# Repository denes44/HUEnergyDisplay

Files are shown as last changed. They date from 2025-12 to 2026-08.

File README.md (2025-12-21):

# HUEnergyDisplay





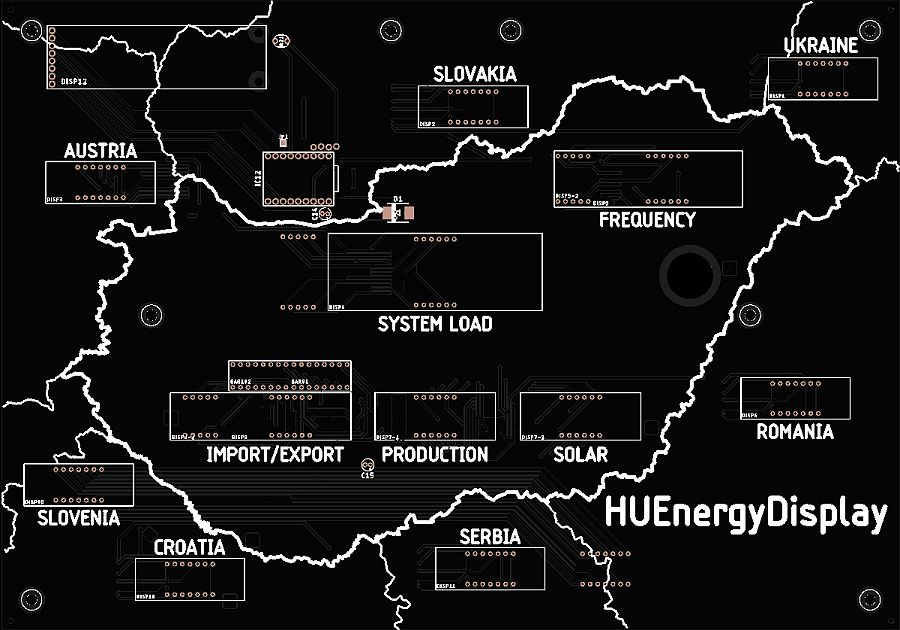
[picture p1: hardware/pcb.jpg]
Design of the PCB


Custom 7 segment display for displaying the hungarian power or natural gas
transmission system.

The display has multiple 7 segment displays for different data arranged around
the map of the country, and it also has a 2.25" TFT display for displaying
status and other miscellaneous data.

| **Power** | **Gas** |
| --- | --- |
| System load | Total consumption |
| Frequency | Storage container ratio |
| Power plant production | Production |
| Solar production | Storage extraction |
| Import/export to neighbouring contries, and total balance | Import/export to neighbouring contries, and total balance |
| Detailed power plant production on the TFT display | |

If you are looking for the easiest way to **start using your display
under Home Assistant:** ***[Home Assistant Quick Start Guide](HomeAssistant.md)***

## Hardware

The hardware of this project is a 300 mm x 210 mm sized bare PCB,
designed to fit into a picture frame, especially the IKEA RÖDALM.

More information about the hardware (PCB size, WiFi controller, display, etc.),
can be found in the **[hardware](hardware/README.md)** folder.

### ESPHome

The display uses an ESP32-S3 controller and ESPHome as it's firmware.

More information about the ESPHome firmware can be found in the
**[esphome](esphome/README.md)** folder.

## API

The display is using it's own private API, which collect and processes
the neccessary datas, and present it in an easy JSON format to the on-board
controller.

The API requires an API Key. By default, the displays are using the MD5 hash
of the MAC address of the controller as the API Key.

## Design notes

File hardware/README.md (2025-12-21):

# HUEnergyDisplay - Hardware



## PCB Size

Design of the PCB

The size of the PCB is 300 mm x 210 mm.

It fits perfectly in an IKEA RÖDALM 21x30 cm picture frame
(IKEA article number is 005.488.82).
The edge of the PCB is designed to not interfere with the edge
of the picture frame.

There is a template available to drill the holes at the back of the
picture frame, so you can mount the PCB: [pcb_cutout.pdf](pcb_cutout.pdf)

## Schematics

## Controller

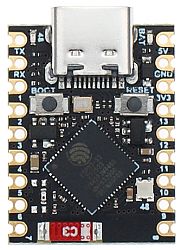
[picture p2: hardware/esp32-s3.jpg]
Photo of the ESP32 controller

The PCB is designed to accomodate an ESP32-S3 SuperMini controller.

The firmware is ESPHome, you can find the configuration to it in the
[esphome](../esphome/README.md) folder.

### GPIO Pinout

| Pin | Function |
| --- | --- |
| GPIO0  | Boot button |
| GPIO1  | MAX7219 CLK |
| GPIO12 | MAX7219 MOSI |
| GPIO13 | MAX7219 CS |
| GPIO5-10 | 2.25" TFT display |
| GPIO4  | Ambient light sensor |
| GPIO48 | Status Led (currently not used) |

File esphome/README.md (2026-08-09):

# HUEnergyDisplay - ESPHome Firmware

Made for ESPHome logo



## Firmware

The default firmware to use is [huenergydisplay-esp32s3.factory.bin](https://github.com/denes44/HUEnergyDisplay/releases/download/esphome-latest/huenergydisplay-esp32s3.factory.bin).
With this firmware you can use [Improv via BLE](https://esphome.io/components/esp32_improv)
or [Improv via Serial](https://esphome.io/components/improv_serial)
to provision your device.

## Configuration

### Factory

The factory firmware uses the [huenergydisplay.factory.yaml](huenergydisplay.factory.yaml)
configuration file.

### ESPHome Dashboard

To import the configuration to your ESPHome Dashboard, use the [huenergydisplay.yaml](huenergydisplay.yaml)
file.

By default this file imports the core configuration from GitHub dynamically.

### Core functionality

Both of these config files import the [huenergydisplay-core.yaml](huenergydisplay-core.yaml)
configuration file which contains the core functionality for the device.

## Firmware update

### Factory

In this configuration mode, the device uses the built-in [HTTP Update platform](https://esphome.io/components/update/http_request.html).

If an update is available, you can update the device from the Web GUI, or from
Home Assistant directly, if you added the device to Home Assistant.

### ESPHome Dashboard

In this configuration mode, a text sensor called `Remote YAML Update`
is provided, to indicate if the remote core yaml configuration is newer than
what's installed on the device.

If you do a firmware install from the dashboard, the build process will use
the new core yaml file from GitHub dynamically.

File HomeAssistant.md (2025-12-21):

# HUEnergyDisplay - Home Assistant Quick Start Guide

## Installing the firmware

If you got your display with the controller and firmware preinstalled,
you can skip to the next step.

## Connect the display to WiFi

### Using Improv Wi-Fi

- With your phone (or other BLE capable device), go to [improv-wifi.com](https://www.improv-wifi.com/)
- At `Improv via BLE` click `Connect device to Wi-Fi`
- Select the device, and click `Pair`
- Enter your Wi-Fi network's credentials (SSID and password) and click `Save`
- The device will now connect to the selected Wi-Fi network

### Connecting to the Wi-Fi AP provided by the device

## Add the display to Home Assistant

After connecting the display to your WiFi network, click on this button
to open the integrations page in Home Assistant:



Home Assistant should automatically recognize the device from the network.

If not, you can manually add itt using the ESPHome integration:



## Using the device in Home Assistant

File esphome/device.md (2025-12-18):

---
title: HUEnergyDisplay
date-published: 2025-12-19
type: misc
standard: global
board: esp32
project-url: https://github.com/denes44/HUEnergyDisplay/tree/main/esphome
made-for-esphome: True
difficulty: 1
---

Custom 7 segment display for displaying the hungarian power or natural gas
transmission system.

The hardware of this project is a 210 mm x 300 mm sized bare PCB,
designed to fit into a picture frame, especially the IKEA RÖDALM.

The display has multiple 7 segment displays for different data arranged around
the map of the country, like: system load, frequency (for power), import/export
for the neighbouring countries, production, etc.

It also has a 2.25" TFT display for displaying status and other miscellaneous
data.

The 7 segment displays are driven by MAX7219 ICs (11 ICs for 12 displays in
total).

## GPIO Pinout

| Pin | Function |
| --- | --- |
| GPIO0  | Boot button |
| GPIO1  | MAX7219 CLK |
| GPIO12 | MAX7219 MOSI |
| GPIO13 | MAX7219 CS |
| GPIO5-10 | 2.25" TFT display |
| GPIO4  | Ambient light sensor |
| GPIO48 | Status Led (currently not used) |

## Basic Configuration

The [Latest configuration](https://github.com/denes44/HUEnergyDisplay/tree/main/esphome)
can be found on the project's GitHub repo.

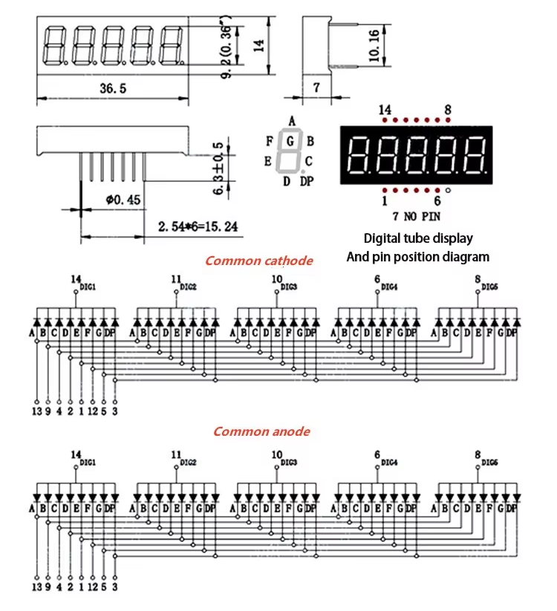
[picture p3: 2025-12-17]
datasheet/display_14mm_5.png

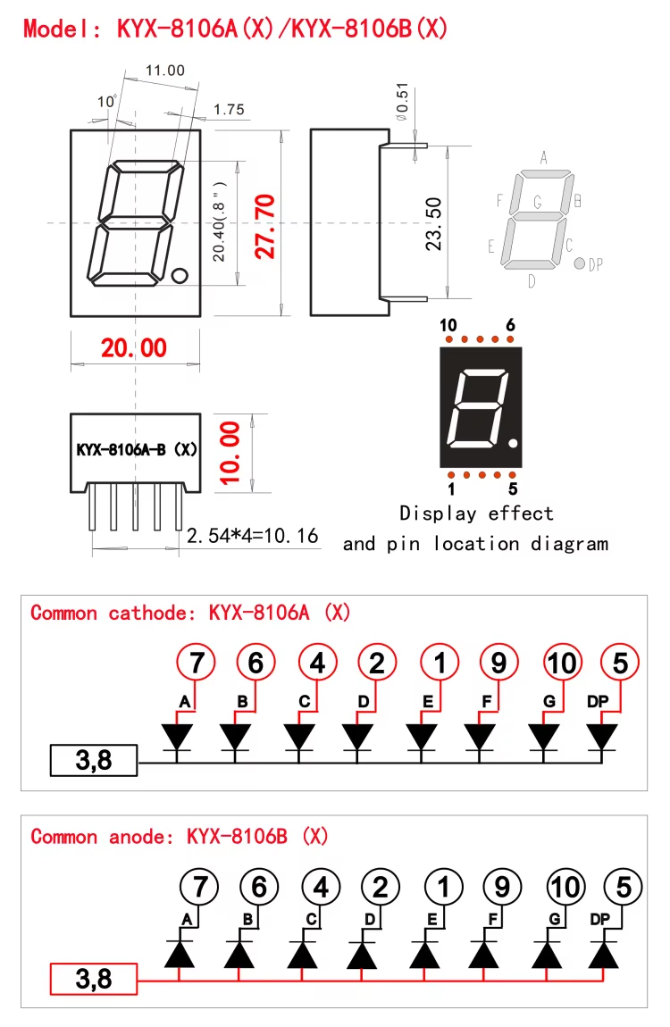
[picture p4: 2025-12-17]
datasheet/display_26mm_1_KYX-8106A_2.png

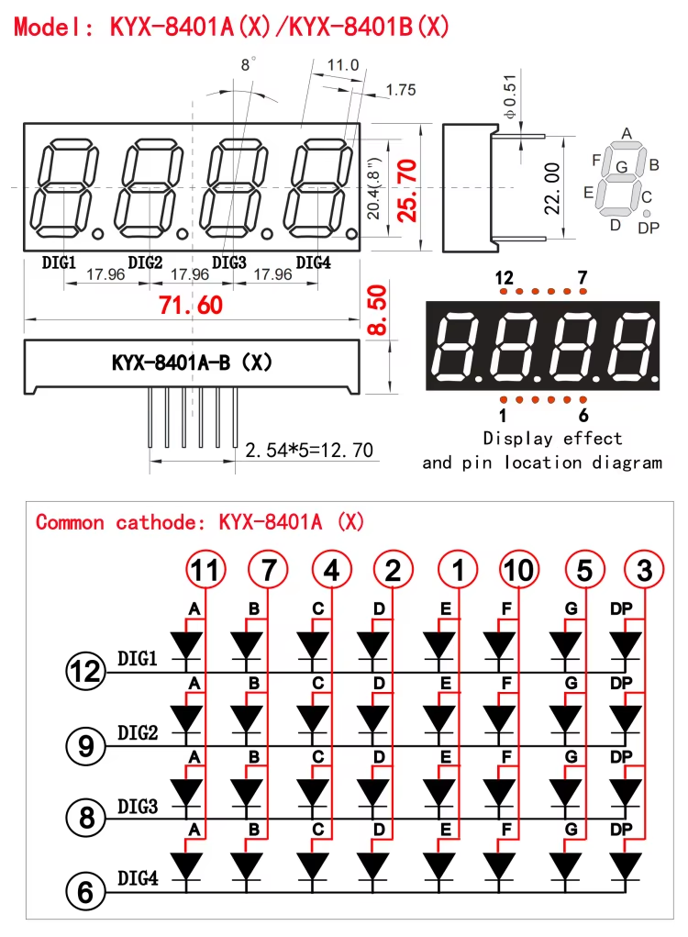
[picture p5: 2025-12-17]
datasheet/display_26mm_4_KYX-8401A_2.png

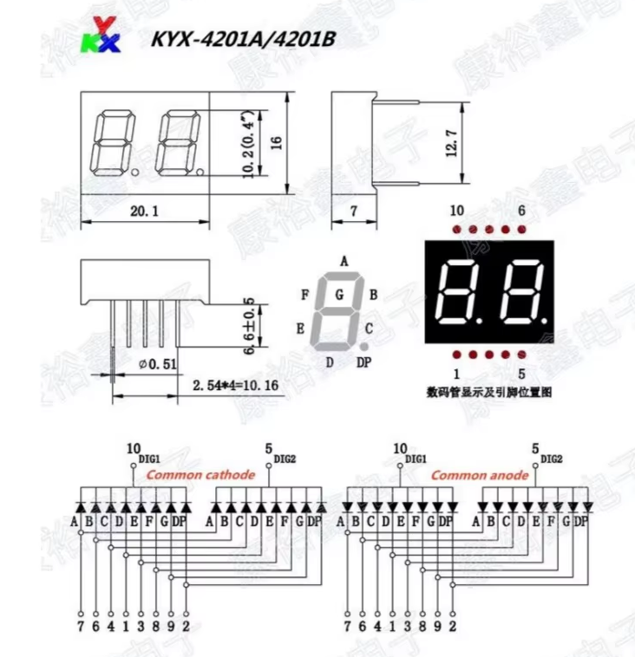
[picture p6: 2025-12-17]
datasheet/display_16mm_2_KYX-4201A.png

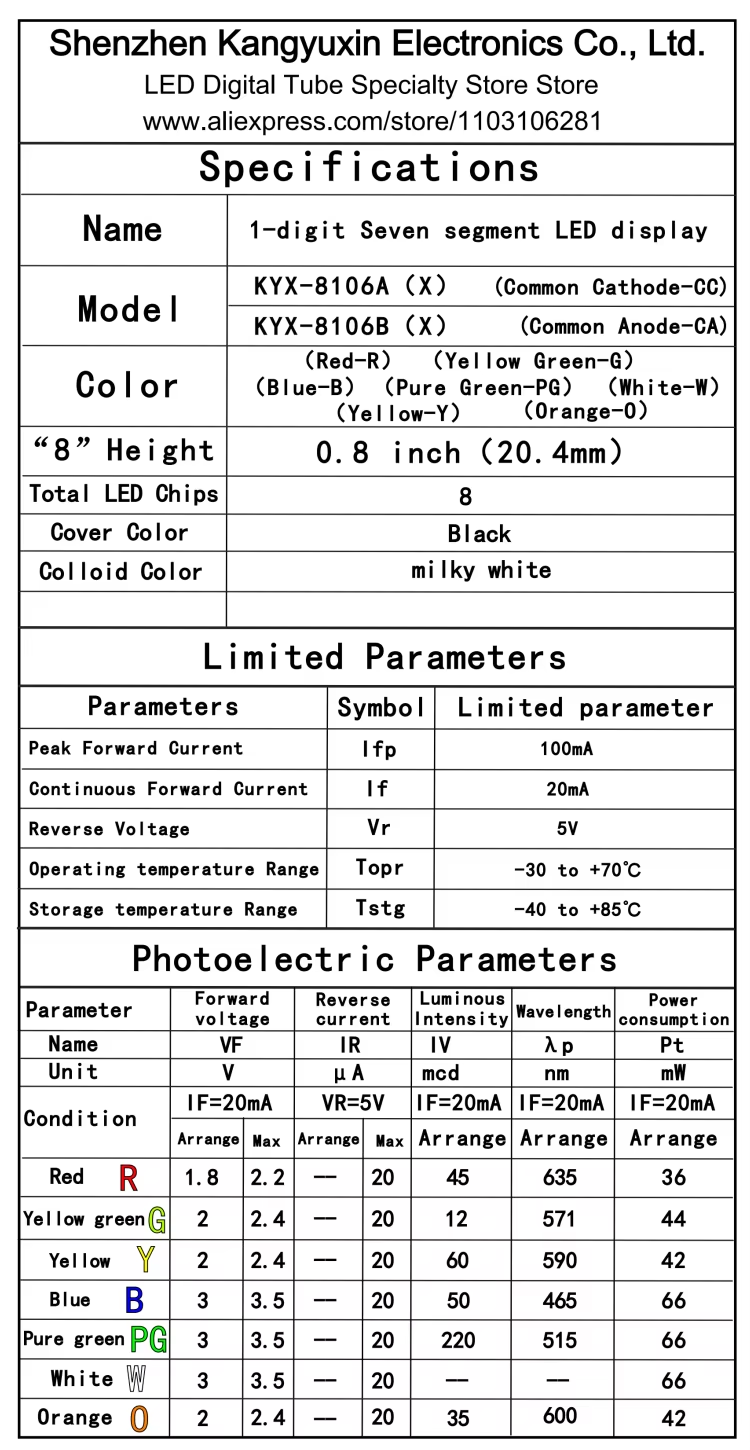
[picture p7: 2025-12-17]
datasheet/display_26mm_1_KYX-8106A_1.png

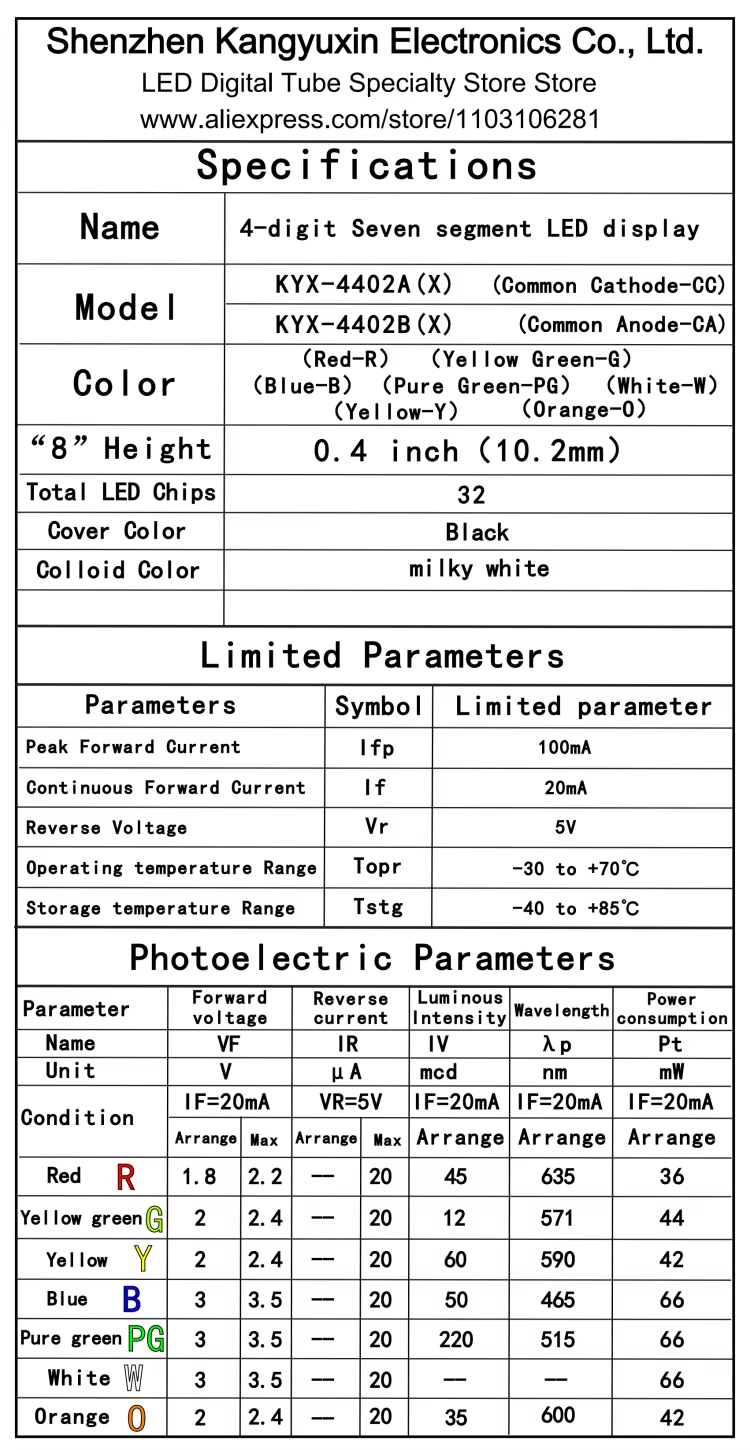
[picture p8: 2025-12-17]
datasheet/display_16mm_4_KYX-4402A_1.png

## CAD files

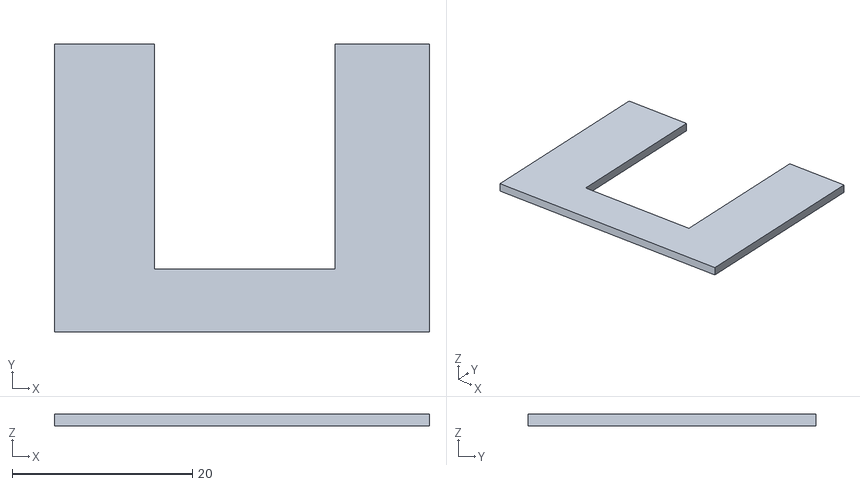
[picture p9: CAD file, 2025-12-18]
3d/14mm_5.stl
41.6 x 32.0 x 1.30

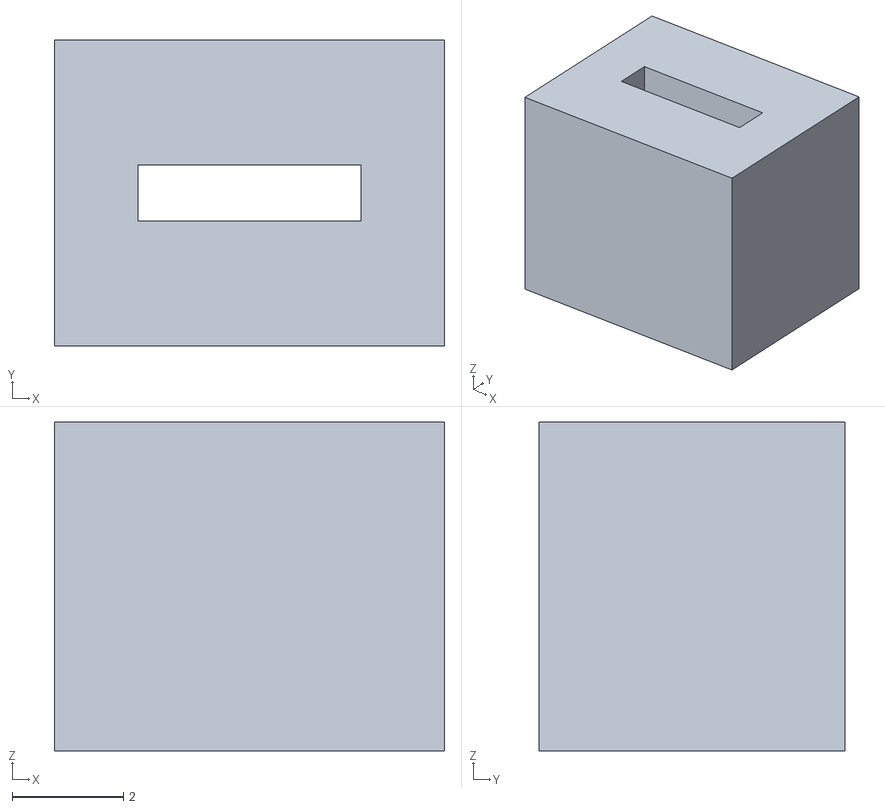
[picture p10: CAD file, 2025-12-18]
3d/sensor_spacer.stl
7.00 x 5.50 x 5.90

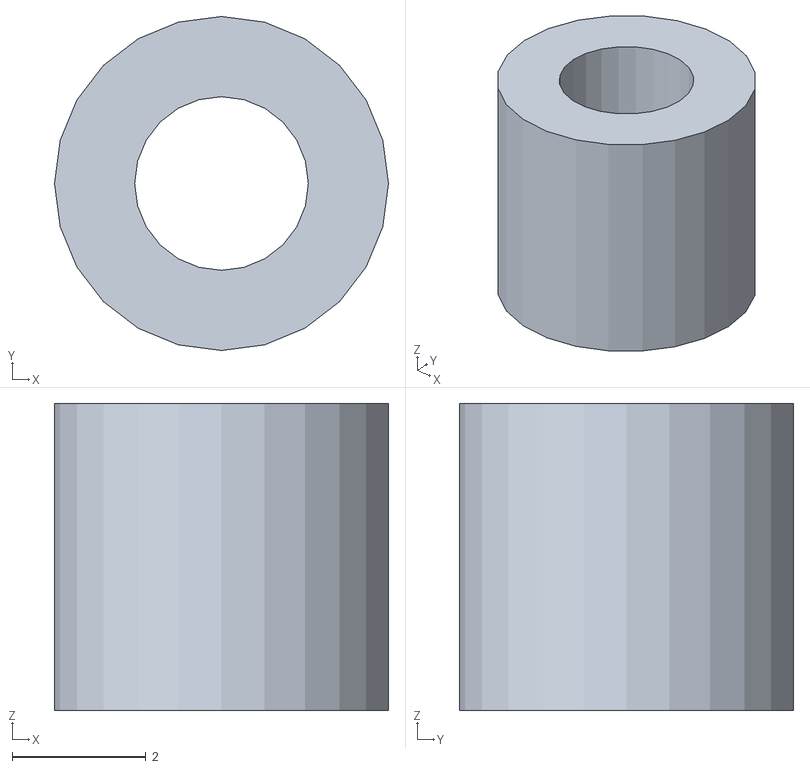
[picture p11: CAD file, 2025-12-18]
3d/tft_spacer.stl
5.00 x 5.00 x 4.60

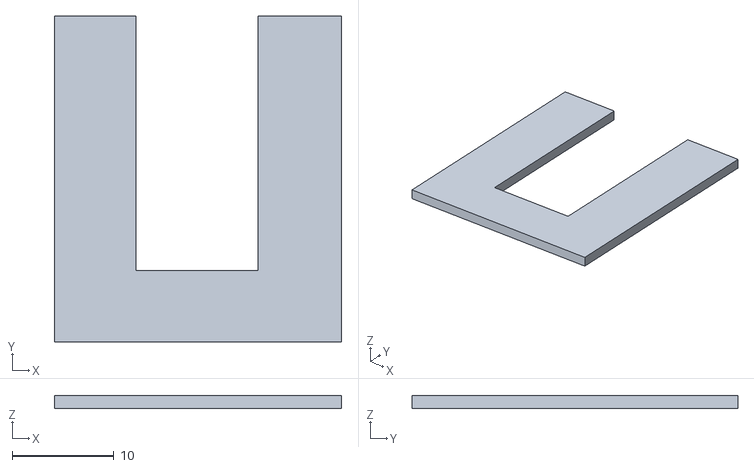
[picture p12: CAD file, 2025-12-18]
3d/16mm_2.stl
28.2 x 32.0 x 1.30

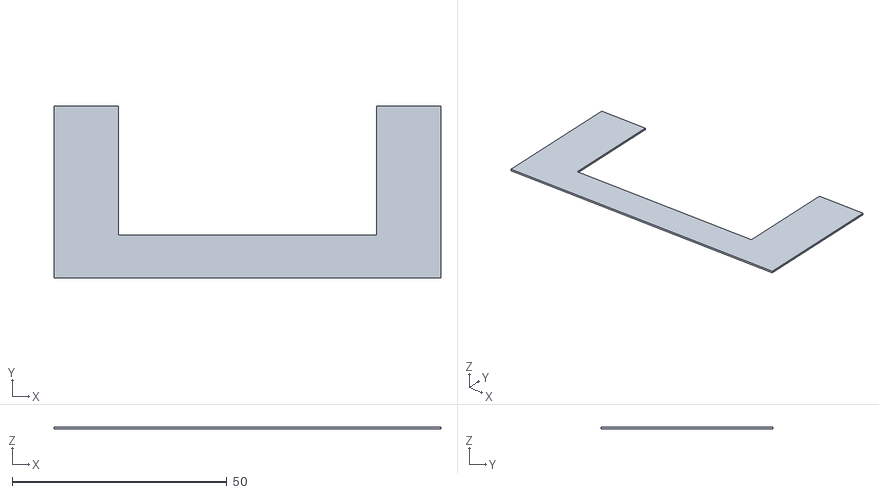
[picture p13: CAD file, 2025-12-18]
3d/19mm_4.stl
90.0 x 40.0 x 0.5

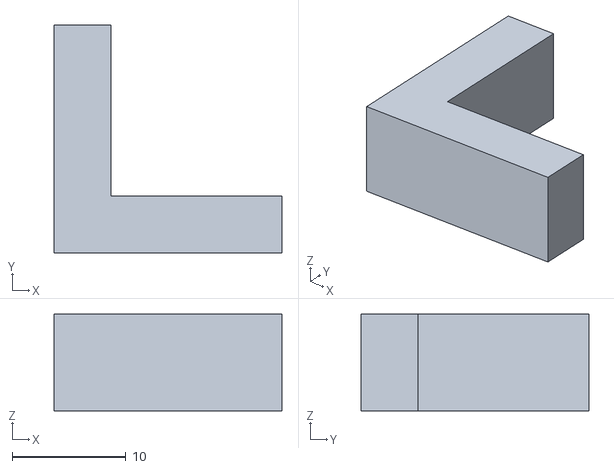
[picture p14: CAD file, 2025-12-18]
3d/corner.stl
20.0 x 20.0 x 8.50

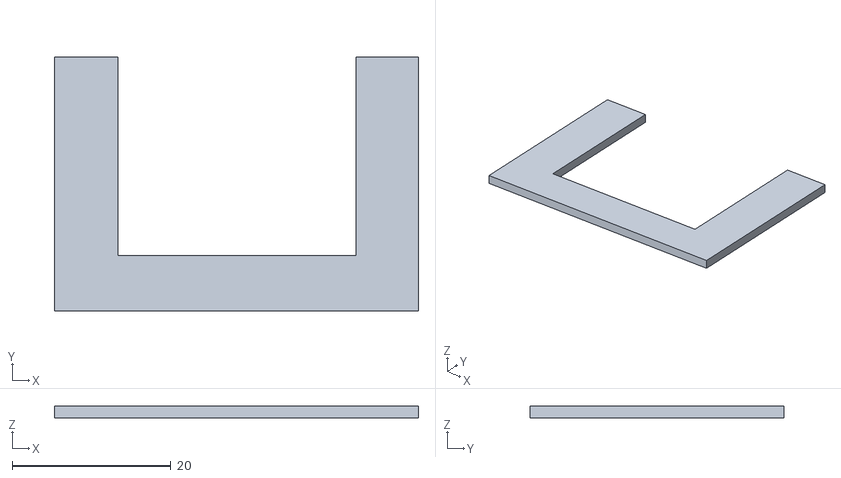
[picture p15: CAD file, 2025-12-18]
3d/16mm_4.stl
45.9 x 32.0 x 1.50

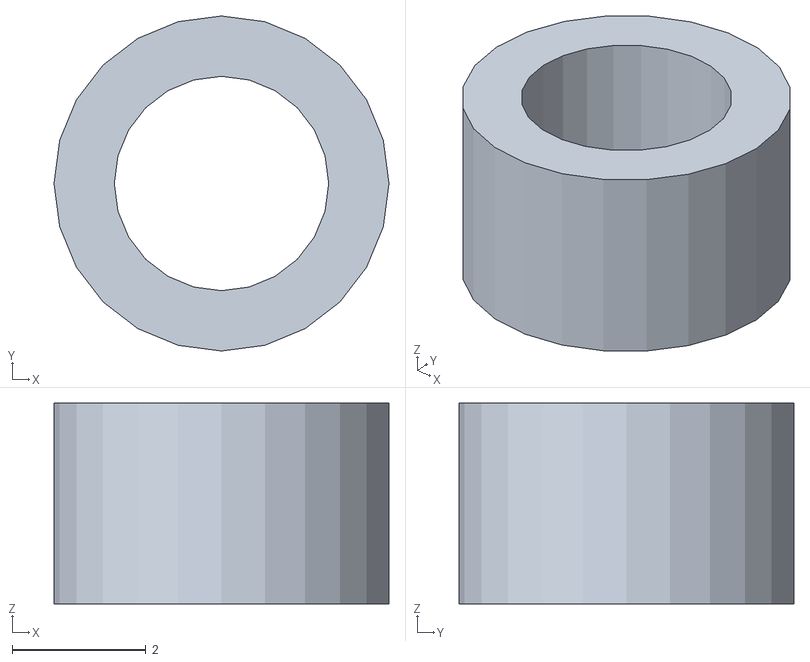
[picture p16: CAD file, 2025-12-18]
3d/back_spacer.stl
5.00 x 5.00 x 3.00

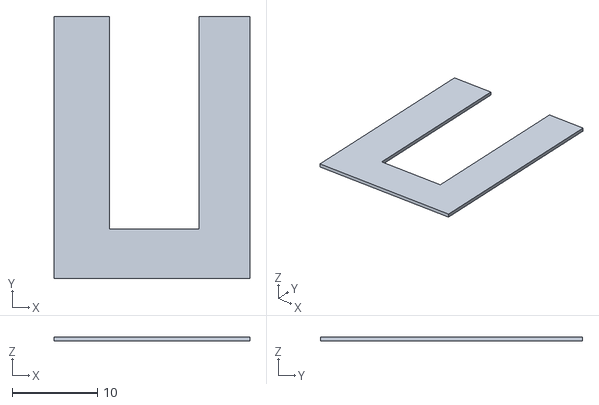
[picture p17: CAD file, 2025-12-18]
3d/19mm_1.stl
23.0 x 30.8 x 0.5

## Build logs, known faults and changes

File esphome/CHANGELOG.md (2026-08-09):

# Changelog for ESPHome firmware

The format is based on [Keep a Changelog](https://keepachangelog.com/en/1.1.0/),
and this project adheres to [Semantic Versioning](https://semver.org/spec/v2.0.0.html).

## [1.3.1] - 2026-08-09

### Fixed

- Fixed an issue with the Home Assistant update module on dashboard imported
  installations
- Changed YAML code to fix display initialization

### Changed

- Changed default device name from `energy-display` to `huenergydisplay`
- Changed YAML format of image resources according to ESP Home upstream changes

## [1.3.0] - 2026-08-02

### Changed

- Changes API paths according to the 1.0.0 version of HUEnergyAPI
- Esphome dependency changes

## [1.2.0] - 2026-01-05

### Changed

- Some of the production type logos were changed (gas, oil, coal, other)
- The production type logos has different colors now instead of all being red
- Fine tuned the HTTP request's parameters to prevent unwanted restarts

## [1.1.0] - 2026-01-04

### Added

- Added settings for different solar modes
  - Now you can choose, how the `System Load`, `Production` and `Solar` displays
    display the Industrial and Prosumer solar data

### Changed

- Changed the solar value source from estimated to ultra-short-term forecast
  - The availability of the estimated values is not reliable, sometimes it
    doesn't updated for more then an hour.
- Changed the CPU frequency to 240 MHz

### Fixed

- Fixed an issue which caused the display to restart without reason

## [1.0.1] - 2025-12-21

### Breaking change
- The device will use the MD5 hash of the MAC address as the API Key,
  instead of a separately provided API Key

### Changed

- The default state of the displays is ON, so they will be on in the factory
  configuration
- Time is only displayed on the TFT display if it's correct (synchronized)
- Moved the error icons on the statusbar one position to the right

### Fixed

- Fixed an issue, where changin the display data to `gas`, didn't change
  the TFT display to the correct page

## [1.0.0] - 2025-12-17

- Initial version

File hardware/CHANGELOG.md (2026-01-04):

# Changelog

The format is based on [Keep a Changelog](https://keepachangelog.com/en/1.1.0/),

## [AAC] - 2025-12-27

### Changed

- Changed DISP5 and DISP5-2 to a single 5 digit display

## [AAB] - 2025-12-26

### Changed

- Moved DISP8-2 a little bit further away from DISP-8
- Moved DISP5-2 a little bit further away from DISP-2
- Changed orientation of C9 to match the others (R1-11, C1-11)

## [AAA] - 2025-12-01

Initial version

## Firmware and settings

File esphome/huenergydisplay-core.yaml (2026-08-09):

##############################################
# HUEnergyDisplay ESPHOME created by denes44 #
# https://github.com/denes44/HUEnergyDisplay #
# Core functionately                         #
##############################################

# ESPHome & Board

esphome:
  name: ${name}
  friendly_name: ${friendly_name}
  min_version: 2025.11.0
  project:
    name: "denes44.HUEnergyDisplay"
    version: 1.3.1
  platformio_options:
    board_build.flash_mode: dio
  on_boot:
    - priority: 600
      then:
        - delay: 5s
        - lambda: "id(lcd_disp).show_page(id(logo2));"
        - delay: 5s
        - lambda: "id(lcd_disp).show_page(id(main_page));"

esp32:
  variant: esp32s3
  flash_size: 4MB
  cpu_frequency: 240MHz
  framework:
    type: esp-idf

psram:
  mode: quad
  speed: 80MHz

logger:

factory_reset:
  resets_required: 5
  max_delay: 10s

http_request:
  timeout: 5s
  watchdog_timeout: 8192ms
  buffer_size_rx: 2048
  buffer_size_tx: 2048

external_components:
  - source:
      type: git
      url: https://github.com/denes44/HUEnergyDisplay
      ref: main
    components: [ max7219 ]

globals:
  # Power - System
  - id: power_system_load
    type: float
  - id: power_system_frequency
    type: float

  # Power - Production
  - id: power_production_total_gross_fact
    type: float
  - id: power_production_total_gross_plan
    type: float
  - id: power_production_biomass
    type: float
  - id: power_production_coal_brown
    type: float
  - id: power_production_coal_hard
    type: float
  - id: power_production_gas
    type: float
  - id: power_production_hspp
    type: float
  - id: power_production_waste
    type: float
  - id: power_production_nuclear
    type: float
  - id: power_production_oil
    type: float
  - id: power_production_other
    type: float
  - id: power_production_other_renewable
    type: float
  - id: power_production_pv
    type: float
  - id: power_production_scpp
    type: float
  - id: power_production_hydro_ror
    type: float
  - id: power_production_hydro_reservoir
    type: float
  - id: power_production_wind
    type: float

  # Power - Import
  - id: power_import_balance
    type: float
  - id: power_import_at
    type: float
  - id: power_import_hr
    type: float
  - id: power_import_ro
    type: float
  - id: power_import_rs
    type: float
  - id: power_import_si
    type: float
  - id: power_import_sk
    type: float
  - id: power_import_ua
    type: float

  # Gas - Consumption
  - id: gas_consumption_total
    type: float

  # Gas - Containers
  - id: gas_containers_ratio
    type: float
  - id: gas_containers_removal
    type: float
  - id: gas_containers_store
    type: float

  # Gas - Import
  - id: gas_import_balance
    type: float
  - id: gas_import_at
    type: float
  - id: gas_import_hr
    type: float
  - id: gas_import_ro
    type: float
  - id: gas_import_rs
    type: float
  - id: gas_import_rs2
    type: float
  - id: gas_import_sk
    type: float
  - id: gas_import_ua
    type: float

  # Gas - Production
  - id: gas_production_total
    type: float

  # Status
  - id: latest_http_status
    type: int
  - id: api_freshness
    type: bool

# WiFi, AP, Network, etc.

wifi:
  id: wifi_id
  output_power: 8.5db
  # Enable fallback hotspot (captive portal) in case wifi connection fails
  ap:
    ssid: ${friendly_name} Fallback AP

captive_portal:


# Home Assistant API

api:

time:
  - platform: homeassistant
    id: api_time
    on_time:
      - seconds: 0
        minutes: "*"
        then:
          - component.update: lcd_disp

# Built in web server

web_server:
  port: 80
  version: 3
  sorting_groups:
    - id: sg_display
      name: "Display Settings"
      sorting_weight: 1
    - id: sg_ambient
      name: "Ambient Light"
      sorting_weight: 2
    - id: sg_status
      name: "WiFi & API Status"
      sorting_weight: 3
    - id: sg_restart
      name: "Restart & Shutdown"
      sorting_weight: 4
    - id: sg_firmware
      name: "Firmware Upgrade"
      sorting_weight: 5


# Generic sensors and buttons

button:
  - platform: restart
    name: Restart
    id: _restart
    entity_category: config
    web_server:
      sorting_weight: 1
      sorting_group_id: sg_restart
  - platform: safe_mode
    name: Restart (Safe Mode)
    id: _restart_safe
    entity_category: config
    web_server:
      sorting_weight: 2
      sorting_group_id: sg_restart
  - platform: shutdown
    name: Shutdown
    id: _shutdown
    entity_category: config
    web_server:
      sorting_weight: 3
      sorting_group_id: sg_restart
  - platform: factory_reset
    name: Factory reset
    id: _factory
    entity_category: config
    web_server:
      sorting_weight: 4
      sorting_group_id: sg_restart
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

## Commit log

2025-12-18 Add 3D files
    [14mm_5.stl, 16mm_2.stl, 16mm_4.stl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]
2025-12-18 Add missing ID to wifi component
    [huenergydisplay-core.yaml]
2026-08-02 Fix display offset config
    [huenergydisplay-core.yaml]
2026-08-02 Fix esphome string comparison change
    [huenergydisplay-core.yaml]
2026-08-08 Fix HA update module
    [huenergydisplay-core.yaml]
2026-08-08 Change default device name
2026-11-01 Only include the used characters in the 7-segment style fonts
    Limit the glyphs of both alarmclock fonts to the characters that are printed, and use 4 bits per pixel for the large one, which saves about 70 kB of flash.
2026-11-01 Pin GitHub Actions to commit SHAs
    Version tags can be moved to different code, like in the tj-actions/changed-files compromise. Pin every action to the commit of its current release, with the version as a comment. This also fixes esphome/build-action, which has no v8 tag, and pins srvaroa/labeler to v1.14.0, because its v1 tag points to an unversioned commit.
2026-11-01 Lock only issues and pull requests
    Since lock-threads v4, discussions are processed by default too, which needs the discussions permission that this workflow doesn't have, so the job failed.
